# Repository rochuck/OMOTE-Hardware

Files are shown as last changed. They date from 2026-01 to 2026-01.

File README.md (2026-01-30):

# OMOTE - Open Universal Remote - Hardware



## Overview

This is my version of the OMOTE project. Please see the original [here](https://github.com/OMOTE-Community/OMOTE-Hardware). It is an ESP32-based open-source universal remote. Its 2.8" capacitive touchscreen provides an intuitive and responsive user interface for switching devices and settings. No hub or docking station is required, as the remote features infrared, Wi‑Fi, and Bluetooth connectivity. With its well-optimized power consumption, OMOTE can run for months on a single charge. 

<div align="center">
  
</div>

### Features
- 2.8" 320×240 px capacitive touchscreen
- Ergonomic, fully 3D-printed case
- Built-in infrared, Wi‑Fi, and Bluetooth
- Press any button or simply lift the remote to wake it
- Up to six months of battery life using a 2000 mAh Li‑Po battery

### This fork of OMOTE

This fork has a few differences:
* The vias on the ESP32 have been enlarged to help reduce manufacturing cost.
* A BOM (`omote.csv`) for Digi‑Key has been included to help source parts.

### Errata

⚠️
The most significant issue (for me) is that the battery terminal connector is reversed compared to shipped lithium‑ion battery packs. After some research it seems that the battery terminal polarity is not standardized; it could have caused serious damage if I hadn't noticed. ⚠️⚡

The current board and BOM have the following issues:
1. The vias under the ESP32 are not connected to ground; this will be modified manually.
1. The USB TVS diodes i ordered (listed in my digikey [BOM](https://github.com/rochuck/OMOTE-Hardware/blob/main/PCB/omote.csv)) are the wrong part. For now, I've removed the part and used 0 Ω resistors.
1. The CH340C was unavailable from Digi‑Key; a CH340G module was used instead. The CH340G requires an external crystal, which was taken from its adapter board.
1. The Li‑ion charger is unavailable from Digi‑Key. An MCP73831T2ACI/OT (SOT‑23‑5) is being used temporarily until the correct part can be sourced from AliExpress.

These changes are shown here:

<div align="center">
  
</div>

## Charger changes

As shown in the diagrams below:

### TP4056
* On the TP4056, the TEMP pin is not used and is grounded.
* The 4.7 kΩ resistor sets the charge current to approximately 300 mA.
* The STANDBY pin goes low when not charging; the LED indicates charging.
* The CHRG pin is pulled low when charging; this is read by the microcontroller.

### MCP73831
* The STAT pin serves as the charging indicator and could be connected to the microcontroller, but it will require a pull-up. We will leave this disconnected for now.
* The PROG resistor at 4.7 kΩ results in a slightly lower charge current — approximately 213 mA at 4.2 V.

### The upshot

| Function | TP4056 pin | MCP pin |
|---|---:|---:|
| VCC | 4 | 4 |
| GND | 3 | 2 |
| PROG | 2 | 5 |
| BATT | 5 | 3 |

<div align="center">
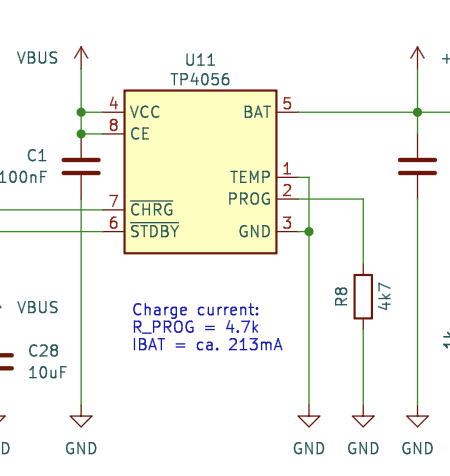
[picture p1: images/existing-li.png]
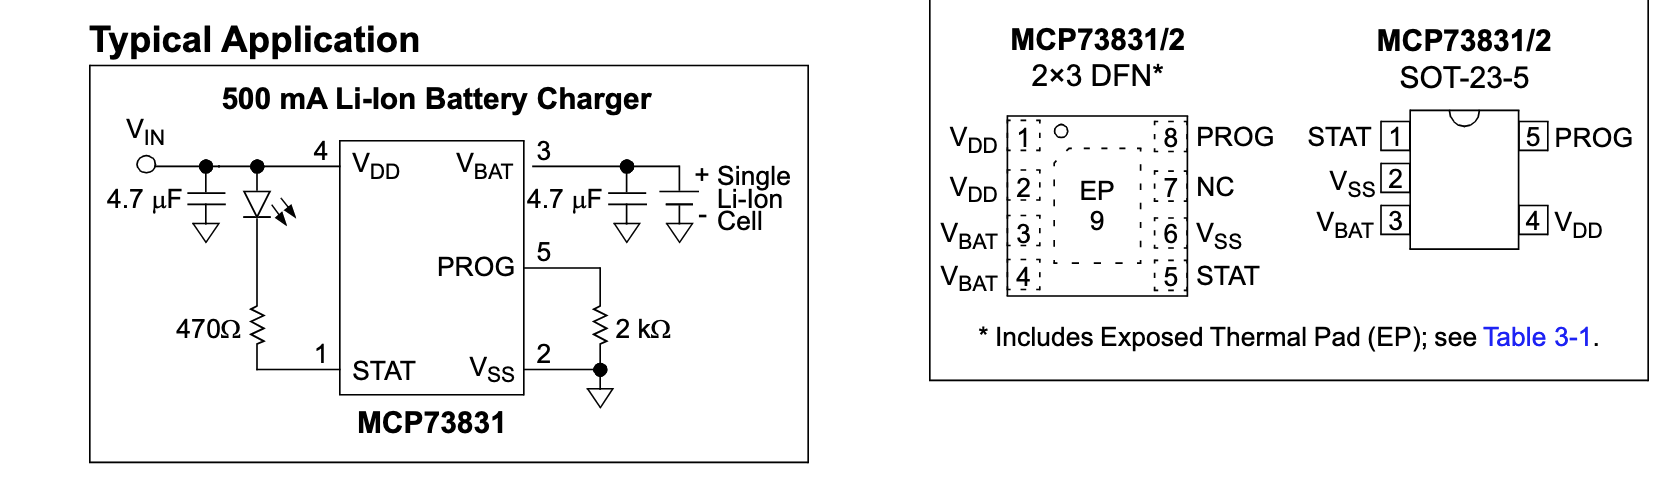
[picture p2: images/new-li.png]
  
</div>

<div align="center">
  
</div>

### Building the hardware

It was easy to order the board from JLCPCB. If I had a do-over, I would have ordered assembled PCBs from JLCPCB using the [instructions](https://github.com/OMOTE-Community/OMOTE-Hardware/wiki/How-to-order-assembled-PCBs) in the Wiki.

I had issues ordering the correct parts, which were hard to find outside of JCSC.

<div align="center">
  
</div>

The [housing and buttons](https://github.com/OMOTE-Community/OMOTE-Hardware/tree/main/CAD) were 3D-printed using PLA. I printed the keypad with 0.2 mm nozzles in dual color; it worked well. The buttons were mostly white so the backlight could show through.

The only problem I had was that the power button in the top right was too thick or positioned incorrectly. I will have to notch the back of the button so that the case will snap closed tightly without continuously pressing the power button.

### Firmware
My fork of the firmware is available at [Chuck's OMOTE ESP32 Firmware](https://github.com/rochuck/OMOTE-Firmware/)

## License

Distributed under the GPL v3 License. See [LICENSE](https://github.com/OMOTE-Community/OMOTE-Hardware/blob/main/LICENSE) for more information.

## Finally

Again, this is just my fork. Please see the original [here](https://github.com/OMOTE-Community/OMOTE-Hardware).

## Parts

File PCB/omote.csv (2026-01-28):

Index | Manufacturer Part Number | Manufacturer Name | Description | Attrition % | Requested Quantity 1 | Pack Quantity 1 | Pack Type 1 | Digi-Key Part Number 1 | Unit Price 1 | Extended Price 1 | Minimum Order Quantity 1 | Product Notes
1 | 150160BS73103 | Würth Elektronik | WL-SMTW SMT MONO-COLOR TOP LED W |  | 50 | 50 | Cut Tape (CT) | 732-150160BS73103CT-ND | 0.29300 | $14.65 | 1
2 | SFH 4547 | ams-OSRAM USA INC. | EMITTER IR 950NM 100MA RADIAL |  | 10 | 10 | Bulk | 475-SFH4547-ND | 0.81600 | $8.16 | 1
3 | JB12F5000R | YAGEO | FUSE 1206 0.5A 63VDC FAST |  | 10 | 10 | Cut Tape (CT) | 13-JB12F5000RCT-ND | 0.19100 | $1.91 | 1
4 | UJ20-C-H-G-SMT-1-P16-TR | Same Sky (Formerly CUI Devices) | USB JACK, TYPE C,2.0, HORIZONTAL |  | 10 | 10 | Cut Tape (CT) | 2223-UJ20-C-H-G-SMT-1-P16-TRCT-ND | 0.56700 | $5.67 | 1
5 | ESP32-S3-WROOM-1U-N16R8 | Espressif Systems | RF TXRX MOD BT WIFIU.FL SMD |  | 3 | 3 | Cut Tape (CT) | 1965-ESP32-S3-WROOM-1U-N16R8CT-ND | 10.11000 | $30.33 | 1
6 | MAX17048G+T10 | Analog Devices Inc./Maxim Integrated | IC BATT MON LI-ION 1CELL 8TDFN |  | 3 | 3 | Cut Tape (CT) | MAX17048G+T10CT-ND | 5.58000 | $16.74 | 1 | Non Cancellable Non Returnable.
7 | USBLC6-4SC6-EV | EVVO | TVS DIODE 5VWM 13VC SOT236 |  | 10 | 10 | Cut Tape (CT) | 5272-USBLC6-4SC6-EVCT-ND | 0.47700 | $4.77 | 1
8 | XC6220B331MR-G | Torex Semiconductor Ltd | IC REG LINEAR 3.3V 1A SOT-25-5 |  | 10 | 10 | Cut Tape (CT) | 893-1133-1-ND | 1.48500 | $14.85 | 1
9 | TPB4056A20-ES1R | 3PEAK | LINEAR BATTERY CHARGER 1 CELL 8- |  | 10 | 10 | Cut Tape (CT) | 5503-TPB4056A20-ES1RCT-ND | 0.50700 | $5.07 | 1
10 | DW01A | Shenzhen Slkormicro Semicon Co., Ltd. | 1.5V~10V LITHIUM BATTERY 1 SOT-2 |  | 100 | 100 | Cut Tape (CT) | 5399-DW01ACT-ND | 0.02510 | $2.51 | 1
11 | TCA8418RTWR | Texas Instruments | IC INTERFACE SPECIALIZED 24WQFN |  | 3 | 3 | Cut Tape (CT) | 296-25223-1-ND | 2.88000 | $8.64 | 1
12 | TL3342F160QG/TR | E-Switch | SWITCH TACTILE SPST-NO 0.05A 12V |  | 100 | 100 | Cut Tape (CT) | EG2531CT-ND | 0.64260 | $64.26 | 1
13 | MBT3904DW1T1G | onsemi | TRANS 2NPN 40V 200MA SC88/SC70 |  | 100 | 100 | Cut Tape (CT) | MBT3904DW1T1GOSCT-ND | 0.10270 | $10.27 | 1
14 | DMG2301L-7 | Diodes Incorporated | MOSFET P-CH 20V 3A SOT23 |  | 100 | 100 | Cut Tape (CT) | DMG2301L-7DICT-ND | 0.14460 | $14.46 | 1
15 | DMG9926UDM-7 | Diodes Incorporated | MOSFET 2N-CH 20V 4.2A SOT26 |  | 10 | 10 | Cut Tape (CT) | DMG9926UDMDICT-ND | 0.71000 | $7.10 | 1
16 | B2B-PH-SM4-TB | JST Sales America Inc. | CONN HEADER SMD 2POS 2MM |  | 10 | 10 | Cut Tape (CT) | 455-B2B-PH-SM4-TBCT-ND | 0.56500 | $5.65 | 1
17 | TSSP77038TT | Vishay Semiconductor Opto Division | SENSOR REMOTE REC 38.0KHZ 40M |  | 3 | 3 | Cut Tape (CT) | TSSP77038TCT-ND | 2.88000 | $8.64 | 1
18 | LIS3DHTR | STMicroelectronics | ACCEL 2-16G I2C/SPI 16LGA |  | 5 | 5 | Cut Tape (CT) | 497-10613-1-ND | 2.03800 | $10.19 | 1
19 | 2770 | Adafruit Industries LLC | GRAPHIC DISPLAY TFT RGB 2.8" |  | 3 | 3 | Bulk | 1528-2770AD-ND | 30.76000 | $92.28 | 1
20 | 62684-502100ALF | Amphenol ICC (FCI) | CONN FPC TOP 50POS 0.5MM R/A |  | 3 | 3 | Cut Tape (CT) | 609-1202-1-ND | 1.08000 | $3.24 | 1

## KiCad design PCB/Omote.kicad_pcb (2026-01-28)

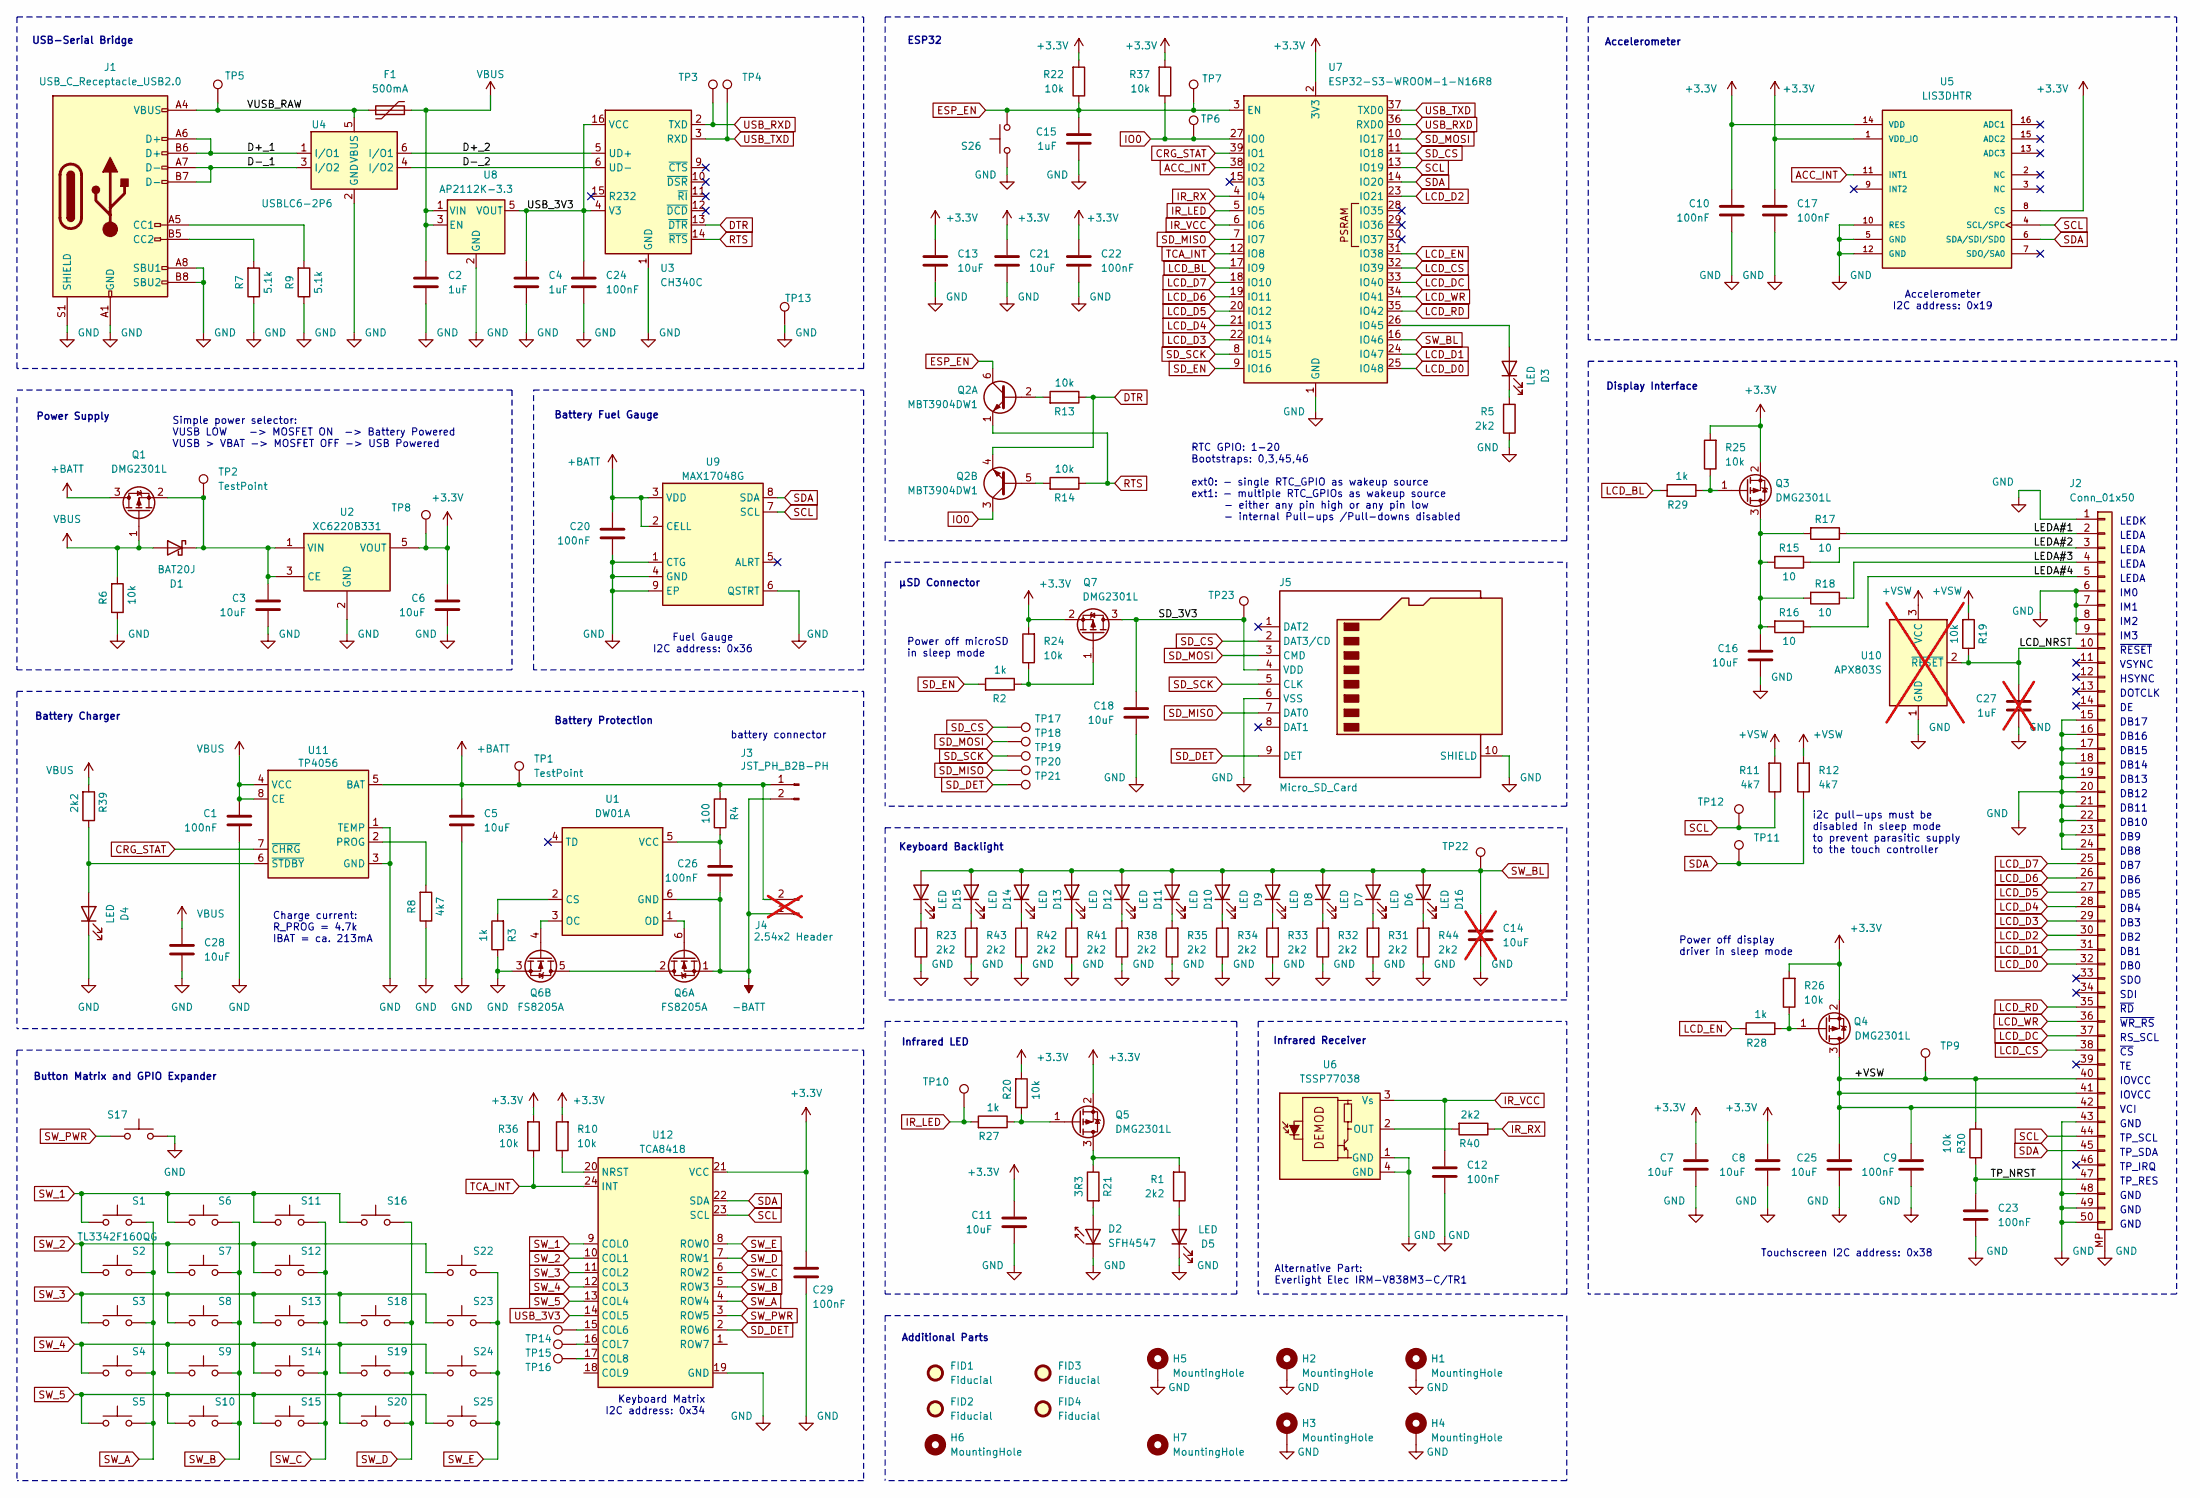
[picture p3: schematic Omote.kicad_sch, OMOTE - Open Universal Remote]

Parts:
C1, C9, C10, C12, C17, C20, C22, C23, C24, C26, C29: 100nF; C_0603_1608Metric; LCSC C1591
C2, C4, C15: 1uF; C_0603_1608Metric; LCSC C15849
C3, C5, C6, C7, C8, C11, C13, C16, C18, C21, C25, C28: 10uF; C_0805_2012Metric; LCSC C15850
C14: 10uF; C_0805_2012Metric; LCSC C15850; not fitted
C27: 1uF; C_0603_1608Metric; not fitted
D1: BAT20J; D_SOD-323; LCSC C155590
D2: SFH4547; LED_5mm_Side_Mount; LCSC C405273
D3, D4, D5: LED; LED_0603_1608Metric; LCSC C965807
D6, D7, D8, D9, D10, D11, D12, D13, D14, D15, D16: LED; LED_0603_1608Metric; LCSC C84265
F1: 500mA; Fuse_1206_3216Metric_Pad1.42x1.75mm_HandSolder; LCSC C220146
FID1, FID2, FID3, FID4: Fiducial; Fiducial_1mm_Mask2mm
H1, H2, H3, H5: MountingHole; MountingHole_3.2mm_M3_Pad_Via
H4: MountingHole; MountingHole_3.2mm_M3
H6, H7: MountingHole; MountingHole_2.5mm
J1: USB_C_Receptacle_USB2.0; USB_C_Receptacle_HRO_TYPE-C-31-M-12; LCSC C2982555
J2: Conn_01x50; TFT_2.83IN_240X320_50PIN; LCSC C11098
J3: JST_PH_B2B-PH; JST_PH_B2B-PH-SM4-TB_1x02-1MP_P2.00mm_Vertical; LCSC C160352
J4: 2.54x2 Header; PinHeader_1x02_P2.54mm_Vertical; not fitted
J5: Micro_SD_Card; MicroSD Slot TF-01A; LCSC C20613191
Q1, Q3, Q4, Q5, Q7: DMG2301L; SOT-23; LCSC C102619
Q2: MBT3904DW1; SOT-363_SC-70-6; LCSC C110150
Q6: FS8205A; SOT-23-6; LCSC C908265
R1, R5, R23, R31, R32, R33, R34, R35, R38, R39, R40, R41, R42, R43, R44: 2k2; R_0603_1608Metric; LCSC C114662
R2, R3, R27, R28, R29: 1k; R_0603_1608Metric; LCSC C22548
R4: 100; R_0603_1608Metric; LCSC C125923
R6, R10, R13, R14, R19, R20, R22, R24, R25, R26, R30, R36, R37: 10k; R_0603_1608Metric; LCSC C98220
R7, R9: 5.1k; R_0603_1608Metric; LCSC C105580
R8, R11, R12: 4k7; R_0603_1608Metric; LCSC C99782
R15, R16, R17, R18: 10; R_0603_1608Metric; LCSC C109318
R21: 3R3; R_0805_2012Metric; LCSC C2849062
S1, S2, S3, S4, S5, S6, S7, S8, S9, S10, S11, S12, S13, S14, S15, S16, S17, S18, S19, S20, S22, S23, S24, S25, S26: TL3342F160QG; SW_SPST_TL3342; LCSC C778172
TP1, TP2, TP3, TP4, TP5, TP6, TP7, TP8, TP9, TP10, TP11, TP12, TP13, TP14, TP15, TP16, TP17, TP18, TP19, TP20, TP21, TP22, TP23: TestPoint; TestPoint_Pad_D1.5mm
U1: DW01A; SOT-23-6; LCSC C18164398
U2: XC6220B331; SOT-23-5; LCSC C86534
U3: CH340C; SOIC-16_3.9x9.9mm_P1.27mm; LCSC C84681
U4: USBLC6-2P6; SOT-666; LCSC C2827693
U5: LIS3DHTR; XDCR_LIS3DHTR; PARTREV 2; LCSC C15134
U6: TSSP77038; Heimdall vertical; LCSC C3291489
U7: ESP32-S3-WROOM-1-N16R8; ESP32-S3-WROOM-1; LCSC C2913202
U8: AP2112K-3.3; SOT-23-5; LCSC C51118
U9: MAX17048G; TDFN-8-1EP_2x2mm_P0.5mm_EP0.8x1.2mm; LCSC C2682616
U10: APX803S; SOT-23; not fitted
U11: TP4056; Infineon_PG-DSO-8-27_3.9x4.9mm_EP2.65x3mm; LCSC C725790
U12: TCA8418; HVQFN-24-1EP_4x4mm_P0.5mm_EP2.5x2.5mm; LCSC C138713

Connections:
+3.3V: C6.1, C7.2, C8.2, C10.1, C11.2, C13.2, C17.1, C21.2, C22.1, C29.1, Q3.2 (S), Q4.2 (S), Q5.2 (S), Q7.2 (S), R10.2, R20.2, R22.2, R24.2, R25.2, R26.2, R36.2, R37.2, TP8.1, U2.5 (VOUT), U5.1 (VDD_IO), U5.8 (CS), U5.14 (VDD), U7.2 (3V3), U12.21 (VCC)
+BATT: C5.2, C20.1, J3.1, J4.2, Q1.3 (D), R4.2, TP1.1, U9.2 (CELL), U9.3 (VDD), U11.5 (BAT)
+VSW: C9.1, C25.2, J2.40, J2.41, J2.42 (Pin_41), Q4.3 (D), R11.2, R12.2, R19.2, R30.1, TP9.1, U10.3 (VCC)
-BATT: C26.2, J3.2, J4.1, Q6.1 (S), U1.6 (GND)
/D+_1: J1.A6 (D+), J1.B6 (D+), U4.1 (I/O1)
/D+_2: U3.5 (UD+), U4.6 (I/O1)
/D-_1: J1.A7 (D-), J1.B7 (D-), U4.3 (I/O2)
/D-_2: U3.6 (UD-), U4.4 (I/O2)
/LCD_NRST: C27.2, J2.10, R19.1, U10.2 (~RESET)
/LEDA#1: J2.2, R17.1
/LEDA#2: J2.3, R15.1
/LEDA#3: J2.4, R18.1
/LEDA#4: J2.5, R16.1
/SD_3V3: C18.2, J5.4 (VDD), Q7.3 (D), TP23.1
/TP_NRST: C23.2, J2.47, R30.2
/VUSB_RAW: F1.1, J1.A4 (VBUS), J1.A9 (VBUS), J1.B4 (VBUS), J1.B9 (VBUS), TP5.1, U4.5 (VBUS)
ACC_INT: U5.11 (INT1), U7.38 (IO2)
CRG_STAT: U7.39 (IO1), U11.7 (~CHRG)
DTR: Q2.4 (E2), R13.1, U3.13 (~DTR)
ESP_EN: C15.2, Q2.6 (C1), R22.1, S26.2, TP7.1, U7.3 (EN)
GND: C1.2, C2.2, C3.1, C4.2, C5.1, C6.2, C7.1, C8.1, C9.2, C10.2, C11.1, C12.2, C13.1, C14.1, C15.1, C16.1, C17.2, C18.1, C20.2, C21.1, C22.2, C23.1, C24.2, C25.1, C27.1, C28.1, C29.2, D2.1 (K), D4.1 (K), D5.1 (K), H1.1, H2.1, H3.1, H4.1, H5.1, J1.A1 (GND), J1.A8 (SBU1), J1.A12 (GND), J1.B1 (GND), J1.B8 (SBU2), J1.B12 (GND), J1.S1 (SHIELD), J2.1, J2.6, J2.7, J2.8, J2.9, J2.15, J2.16, J2.17, J2.18, J2.19, J2.20, J2.21, J2.22, J2.23, J2.24, J2.43, J2.48, J2.49, J2.50, J2.MP, J5.6 (VSS), J5.10 (SHIELD), Q6.3 (S), R3.1, R5.1, R6.1, R7.1, R8.1, R9.1, R23.1, R31.1, R32.1, R33.1, R34.1, R35.1, R38.1, R41.1, R42.1, R43.1, R44.1, S17.1, S26.1, TP13.1, U2.2 (GND), U3.1 (GND), U4.2 (GND), U5.5 (GND), U5.10 (RES), U5.12 (GND), U6.1 (GND), U6.4 (GND), U7.1 (GND), U7.40 (GND), U7.41 (GND), U8.2 (GND), U9.1 (CTG), U9.4 (GND), U9.6 (QSTRT), U9.9 (EP), U10.1 (GND), U11.1 (TEMP), U11.3 (GND), U11.9 (GND), U12.19 (GND)
IO0: Q2.3 (C2), R37.1, TP6.1, U7.27 (IO0)
IR_LED: R27.2, TP10.1, U7.5 (IO5)
IR_RX: R40.1, U7.4 (IO4)
IR_VCC: C12.1, U6.3 (Vs), U7.6 (IO6)
LCD_BL: R29.2, U7.17 (IO9)
LCD_CS: J2.38, U7.32 (IO39)
LCD_D0: J2.32, U7.25 (IO48)
LCD_D1: J2.31, U7.24 (IO47)
LCD_D2: J2.30, U7.23 (IO21)
LCD_D3: J2.29, U7.22 (IO14)
LCD_D4: J2.28, U7.21 (IO13)
LCD_D5: J2.27, U7.20 (IO12)
LCD_D6: J2.26, U7.19 (IO11)
LCD_D7: J2.25, U7.18 (IO10)
LCD_DC: J2.37, U7.33 (IO40)
LCD_EN: R28.2, U7.31 (IO38)
LCD_RD: J2.35, U7.35 (IO42)
LCD_WR: J2.36, U7.34 (IO41)
unnamed: C3.2, D1.1 (K), Q1.2 (S), TP2.1, U2.1 (VIN), U2.3 (CE)
unnamed: D2.2 (A), R21.2
unnamed: D3.2 (A), U7.26 (IO45)
unnamed: D3.1 (K), R5.2
unnamed: D4.2 (A), R39.1, U11.6 (~STDBY)
unnamed: D5.2 (A), R1.1
unnamed: D6.1 (K), R31.2
unnamed: D7.1 (K), R32.2
unnamed: D8.1 (K), R33.2
unnamed: D9.1 (K), R34.2
unnamed: D10.1 (K), R35.2
unnamed: D11.1 (K), R38.2
unnamed: D12.1 (K), R41.2
unnamed: D13.1 (K), R42.2
unnamed: D14.1 (K), R43.2
unnamed: D15.1 (K), R23.2
unnamed: D16.1 (K), R44.2
unnamed: J1.A5 (CC1), R9.2
unnamed: J1.B5 (CC2), R7.2
unnamed: Q2.2 (B1), R13.2
unnamed: Q2.5 (B2), R14.2
unnamed: C16.2, Q3.3 (D), R15.2, R16.2, R17.2, R18.2
unnamed: Q3.1 (G), R25.1, R29.1
unnamed: Q4.1 (G), R26.1, R28.1
unnamed: Q5.3 (D), R1.2, R21.1
unnamed: Q5.1 (G), R20.1, R27.1
unnamed: Q6.2 (D), Q6.5 (D)
unnamed: Q6.6 (G), U1.1 (OD)
unnamed: Q6.4 (G), U1.3 (OC)
unnamed: Q7.1 (G), R2.1, R24.1
unnamed: R3.2, U1.2 (CS)
unnamed: C26.1, R4.1, U1.5 (VCC)
unnamed: R40.2, U6.2 (OUT)
unnamed: R8.2, U11.2 (PROG)
unnamed: TP14.1, U12.15 (COL6)
unnamed: TP15.1, U12.16 (COL7)
unnamed: TP16.1, U12.17 (COL8)
unnamed: R10.1, U12.20 (NRST)
RTS: Q2.1 (E1), R14.1, U3.14 (~RTS)
SCL: J2.44, R11.1, TP12.1, U5.4 (SCL/SPC), U7.13 (IO19), U9.7 (SCL), U12.23 (SCL)
SDA: J2.45, R12.1, TP11.1, U5.6 (SDA/SDI/SDO), U7.14 (IO20), U9.8 (SDA), U12.22 (SDA)
SD_CS: J5.2 (DAT3/CD), TP17.1, U7.11 (IO18)
SD_DET: J5.9 (DET), TP21.1, U12.2 (ROW6)
SD_EN: R2.2, U7.9 (IO16)
SD_MISO: J5.7 (DAT0), TP20.1, U7.7 (IO7)
SD_MOSI: J5.3 (CMD), TP18.1, U7.10 (IO17)
SD_SCK: J5.5 (CLK), TP19.1, U7.8 (IO15)
SW_1: S1.1, S6.1, S11.1, S16.1, U12.9 (COL0)
SW_2: S2.1, S7.1, S12.1, S22.1, U12.10 (COL1)
SW_3: S3.1, S8.1, S13.1, S18.1, S23.1, U12.11 (COL2)
SW_4: S4.1, S9.1, S14.1, S19.1, S24.1, U12.12 (COL3)
SW_5: S5.1, S10.1, S15.1, S20.1, S25.1, U12.13 (COL4)
SW_A: S1.2, S2.2, S3.2, S4.2, S5.2, U12.4 (ROW4)
SW_B: S6.2, S7.2, S8.2, S9.2, S10.2, U12.5 (ROW3)
SW_BL: C14.2, D6.2 (A), D7.2 (A), D8.2 (A), D9.2 (A), D10.2 (A), D11.2 (A), D12.2 (A), D13.2 (A), D14.2 (A), D15.2 (A), D16.2 (A), TP22.1, U7.16 (IO46)
SW_C: S11.2, S12.2, S13.2, S14.2, S15.2, U12.6 (ROW2)
SW_D: S16.2, S18.2, S19.2, S20.2, U12.7 (ROW1)
SW_E: S22.2, S23.2, S24.2, S25.2, U12.8 (ROW0)
SW_PWR: S17.2, U12.3 (ROW5)
TCA_INT: R36.1, U7.12 (IO8), U12.24 (INT)
USB_3V3: C4.1, C24.1, U3.4 (V3), U3.16 (VCC), U8.5 (VOUT), U12.14 (COL5)
USB_RXD: TP3.1, U3.2 (TXD), U7.36 (RXD0)
USB_TXD: TP4.1, U3.3 (RXD), U7.37 (TXD0)
VBUS: C1.1, C2.1, C28.2, D1.2 (A), F1.2, Q1.1 (G), R6.2, R39.2, U8.1 (VIN), U8.3 (EN), U11.4 (VCC), U11.8 (CE)

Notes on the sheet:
DB6
Accelerometer I2C address: 0x19
DB11
DB14
IM2
DB10
Infrared Receiver
Display Interface
LEDA
DB0
GND
DB16
Alternative Part: Everlight Elec IRM-V838M3-C/TR1
TP_RES
TP_IRQ
LEDK
IM1
IOVCC
Battery Fuel Gauge
~{RESET}
ESP32
RTC GPIO: 1-20 Bootstraps: 0,3,45,46 ext0: - single RTC_GPIO as wakeup source ext1: - multiple RTC_GPIOs as wakeup source - either any pin high or any pin low - internal Pull-ups /Pull-downs disabled
Battery Protection
IM3
DB5
Additional Parts
USB-Serial Bridge
Charge current: R_PROG = 4.7k IBAT = ca. 213mA
DB17
TP_SDA
DB7
DB12
DB1
DOTCLK
~{WR_RS}
Infrared LED
µSD Connector
SDI
DB13
DB4

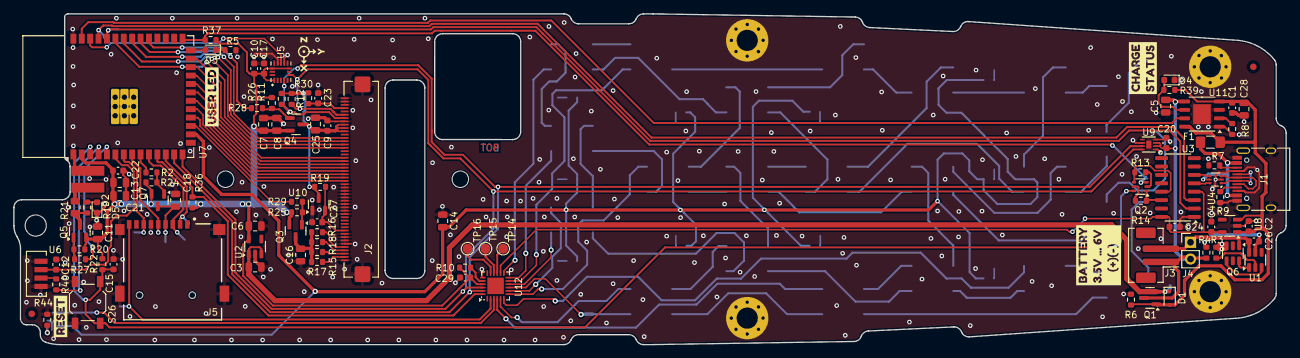
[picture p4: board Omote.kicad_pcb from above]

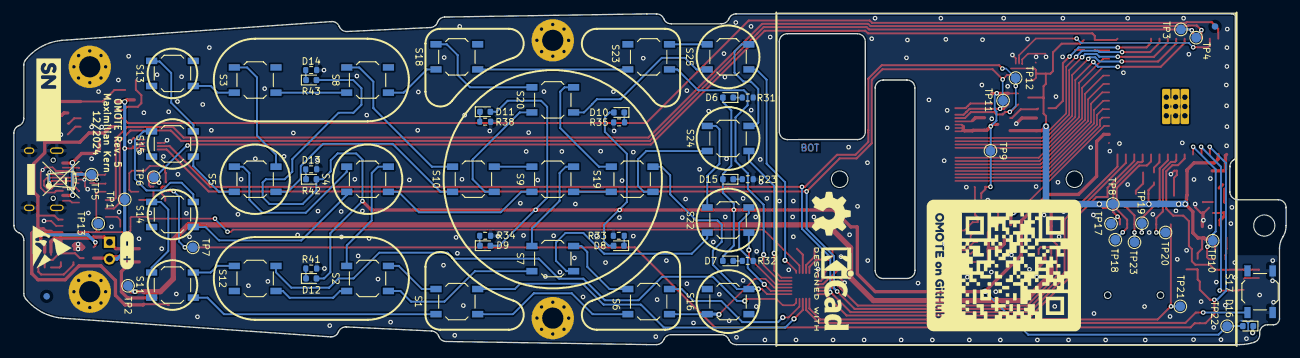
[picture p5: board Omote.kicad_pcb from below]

Board: 2 copper layers, 192.4 x 50.0 mm, 181 parts (69 on the bottom side), 103 nets.

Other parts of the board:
kibuzzard-63D97EAF: G***; kibuzzard-63D97EAF
kibuzzard-64A91BF0: G***; kibuzzard-64A91BF0
kibuzzard-64A91C1C: G***; kibuzzard-64A91C1C
kibuzzard-64A91C24: G***; kibuzzard-64A91C24
kibuzzard-643EE5B9: G***; kibuzzard-643EE5B9
kibuzzard-643EE8B3: G***; kibuzzard-643EE8B3
kibuzzard-643EE46C: G***; kibuzzard-643EE46C
kibuzzard-643EE600: G***; kibuzzard-643EE600
kibuzzard-644014FA: G***; kibuzzard-644014FA

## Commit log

2026-01-28 shrink vias under esp32-S3 for cheaper board run
    [Omote.kicad_pcb, Omote.kicad_sch]
2026-01-28 Document errata on my prototype build.
    [omote.csv]
2026-01-28 update with working battery charger
2026-01-30 clarified my bom issues
